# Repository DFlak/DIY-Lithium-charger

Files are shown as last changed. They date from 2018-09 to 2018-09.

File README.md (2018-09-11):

# DIY Lithium charger

<b>First of all, I'm not in any way responsible for any damage that 
could be an outcome of using any part of this circuit.
Lithium batteries are dangerous and shouldn't be handled by unexperienced
persona. Never leave your packs unattended.</b>

I'm aiming to develop a cheap, safe, easy to build and multi-channel lithium charger.
Everyone knows that you can already buy things like iMax B6 clones or whatever. Simple answer is 
those chargers only allow you to charge one battery at a time and their balancing current is less than enough
for anyone that built a battery from used or mismatched cells.

Main goals:<b>

    Independent, balanced channels,
    Easy and cheap to expand,
    Possibly the smallest form factor,
    Wide input and output voltage range, 
    Making it safe to use.

Please remember that it is all work in progress.

## Balancer

The circuit used to build this balancer was created by Afdhal Atiff Tan Amin Husaini Tan from the http://www.afdhalatifftan.com/ blog. His work and his results inspired me to create a board from his schematic. The board uses 10mil trace width which is big enough for toner transfer and unskilled person and also plenty of spacing. The only thing worth mentioning is that resistors which form differential amplifier need to have 0.1% or less tolerance. I was succesful at buying 600pcs of 1k resistors from AliExpress and sorting them by using ADS1115 ADC. Basically you're looking for resistor closest to 1k value with a DMM and then you compare this resistor with any unknown 1k5% one. If value gets close enough LED blinks which indicates that its' resistance is close enough to be 1% tolerance. I can share the code and schematic if anyone needs it but its really basic. Sorting 600 resistors took me about 1,5h and yielded 47 1000+-1ohm and 12 1012+-1ohm resistors. 
A thing worth noting is that it doesn't matter if you choose 1012ohm resistors or 980ohm or whatever value. Only thing that matters is that those resistors need to be 0.1% or even closer to each other. 
I've created this design on regular FR4 1,6mm 35um copper clad. Initially I wanted to etch two sides on one-sided clads and then solder them together by vias but it ended up looking like crap and taking way more time that it needed. 
Will post updates with photos as I etch double-sided clad and test this circuit.
- [x] Create prototype PCB
- [x] Get really dissapointed with the results
- [ ] Order some double-sided PCBs
- [ ] Etch and prototype
- [ ] Post results

## The bare bones 

Basically this charger will push current into lithium packs using [LM2596 based step-down converters](https://www.aliexpress.com/item/1Pcs-LM2596S-DC-DC-Constant-Current-Module-LM2596-DC-DC-7V-35V-Step-down-Adjustable-CC/32849005778.html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). They have usefull feature which is constant current mode and low drift floating voltage. However, them being step-down topology they need their Vin to be at least 2,5V greater than output. Anything lower than that can result in unstable operation of such converter. To remedy this problem I utilized [150W DC-DC Boost converter](https://www.aliexpress.com/item/150W-DC-DC-Boost-Converter-Step-Up-Power-Supply-Module-10-32V-To-12-35V-10A/2038554691.html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) which is set to 19,5V, 2,7volts higher than full 4S Li-po pack. 
In order to stack the LM25965 converters I needed to change the orientation of trimpots from vertical to horizontal. It was done easily with a help of solder wick. Converters are held to each other via epoxy glue on top of the electrolytic capacitors. Heat didn't pose any issues while charging at 1.7A x3 packs. Neither LM25965 nor 150W boost converter were hot to the touch. 

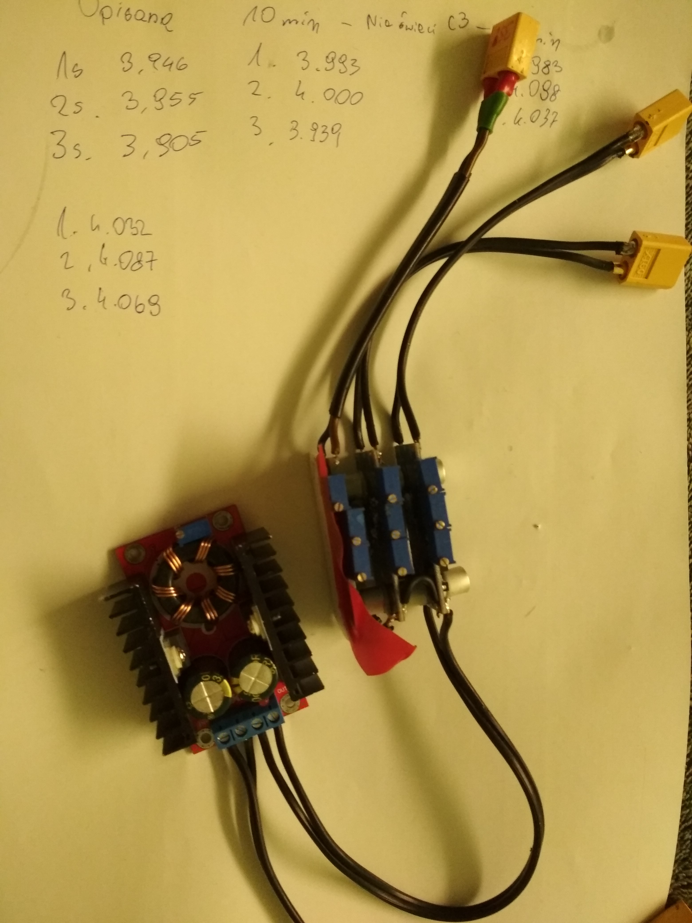
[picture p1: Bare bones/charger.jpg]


I was powering this ciruit from diy-made 4s pack. 
The bare bones of this project are considered done. To expand this charger for more packs you would need to put more LM25965's in parallel keeping in mind the maximum of 150W for each boost converter. My estimate is that one boost converter can supply five charger modules.

## Control, safety and feedback

This charger will use Arduino Nano as a controller. Packs will be switched with a 5V RelPol relays. Each cell will be monitored using [CD74HC4067](https://www.aliexpress.com/item/Smart-Electronics-CD74HC4067-16-Channel-Analog-Digital-Multiplexer-Breakout-Board-Module-for-Arduino/32724398868.html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), calibrated resistive voltage divider and [ADS1115 16bit ADC](https://www.aliexpress.com/item/I2C-ADS1115-ADS1015-16-Bit-ADC-4-channel-Module-with-Programmable-Gain-Amplifier-2-0V-to/32674556200.html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,searchweb201602_4_10065_10068_10843_10059_5016517_10696_100031_5016717_10084_10083_10103_451_10618_452_10304_10307_5016617_10820_10301_10821_5016417,searchweb201603_45,ppcSwitch_5&algo_expid=fb968794-6da6-4dc2-80d7-a833cd81f520-1&algo_pvid=fb968794-6da6-4dc2-80d7-a833cd81f520&transAbTest=ae803_2&priceBeautifyAB=0). I'm planning on adding current monitoring but it all depends whether I can develop reliable and cheap low-side current meter without introducing any more losses. Voltage of each cell will be displayed on regular [16x2 LCD](https://www.aliexpress.com/item/1pcs-lot-New-1602-16x2-Character-LCD-Display-Module-HD44780-Controller-blue-blacklight-IN-STOCK/32328960211.html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,searchweb201602_4_10065_10068_10843_10059_5016517_10696_100031_5016717_10084_10083_10103_451_10618_452_10304_10307_5016617_10820_10301_10821_5016417,searchweb201603_45,ppcSwitch_5&algo_expid=6a017778-b50d-4f92-a064-2eaae25a3f11-0&algo_pvid=6a017778-b50d-4f92-a064-2eaae25a3f11&transAbTest=ae803_2&priceBeautifyAB=0). Arduino will guard if every cell's voltage is in 3.2V < X > 4.2V range. Only then will it allow the relay to connect pack to the charger. Good idea would be to add a capacity meter, capacity limit and charging time limit. First two are dependant on my current meter so I don't know if it will be included.
- [x] Order all of the parts
- [ ] Receive all of the parts 
- [ ] Think of a way to measure current
- [ ] Create schematic
- [ ] Create .brd 
- [ ] Etch and prototype PCB
- [ ] Create arduino code
- [ ] Test the thing thoroughly
- [ ] Post all the files here

### If anyone is interested in helping me feel free to contact me via mail at wtflolrotfl@gmail.com :)

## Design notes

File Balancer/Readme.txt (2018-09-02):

The schematic was made by Afdhal Atiff Tan.
His blog can be found at this link and I encourage you to go take a look.

<b>http://www.afdhalatifftan.com/2017/06/low-cost-active-battery-balancer.html</b>

Board was made by me. It can be viewed by Eagle, I used version 7.7, resistors are THT because it's far easier to source 0.1% THT's than SMD's.

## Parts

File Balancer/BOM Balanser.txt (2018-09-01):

Partlist exported from C:/Users/Jabby/Desktop/Eagle/w trakcie/balanser/balanser 4s drugi prototyp, smd kondziorki.sch at 2018-09-01 18:04

Qty Value                  Device                 Package                Parts                                                  Description                                           MF MPN OC_FARNELL OC_NEWARK
1                          JU05                   JU05                   J1                                                     PIN HEADER                                                   unknown    unknown  
3   100R                   R-EU_M0805             M0805                  R5, R14, R23                                           RESISTOR, European symbol                                                        
6   100n                   C-EUC0805K             C0805K                 C1, C2, C7, C8, C9, C10                                CAPACITOR, European symbol                                                       
6   10k                    R-EU_M0805             M0805                  R7, R8, R16, R17, R25, R26                             RESISTOR, European symbol                                                        
3   10uF                   CPOL-EUE2,5-6E         E2,5-6E                C5, C12, C14                                           POLARIZED CAPACITOR, European symbol                                             
12  1k                     R-EU_0204/7            0204/7                 R1, R2, R3, R4, R10, R11, R12, R13, R19, R20, R21, R22 RESISTOR, European symbol                                                        
6   1k                     R-EU_M0805             M0805                  R6, R9, R15, R18, R24, R27                             RESISTOR, European symbol                                                        
5   2.6A Polyfuse          1812L                  1812L                  F2, F3, F4, F5, F6                                                                                                                      
3   22uF                   CPOL-EUE2,5-6E         E2,5-6E                C6, C11, C13                                           POLARIZED CAPACITOR, European symbol                                             
3   DC-DC-STEP-DOWN-MP2307 DC-DC-STEP-DOWN-MP2307 DC-DC-STEP-DOWN-MP2307 U$1, U$2, U$3                                          DC/DC Step-Down Regulator based on MP2307DN chip                                 
3   LM358D                 LM358D                 SO08                   IC1, IC2, IC3                                          OP AMP also LM158; LM258; LM2904                                                 
3   LSP10                  LSP10                  LSP10                  VFB1, VFB2, VFB3                                       SOLDER PAD drill 1.0 mm, distributor Buerklin, 12H555

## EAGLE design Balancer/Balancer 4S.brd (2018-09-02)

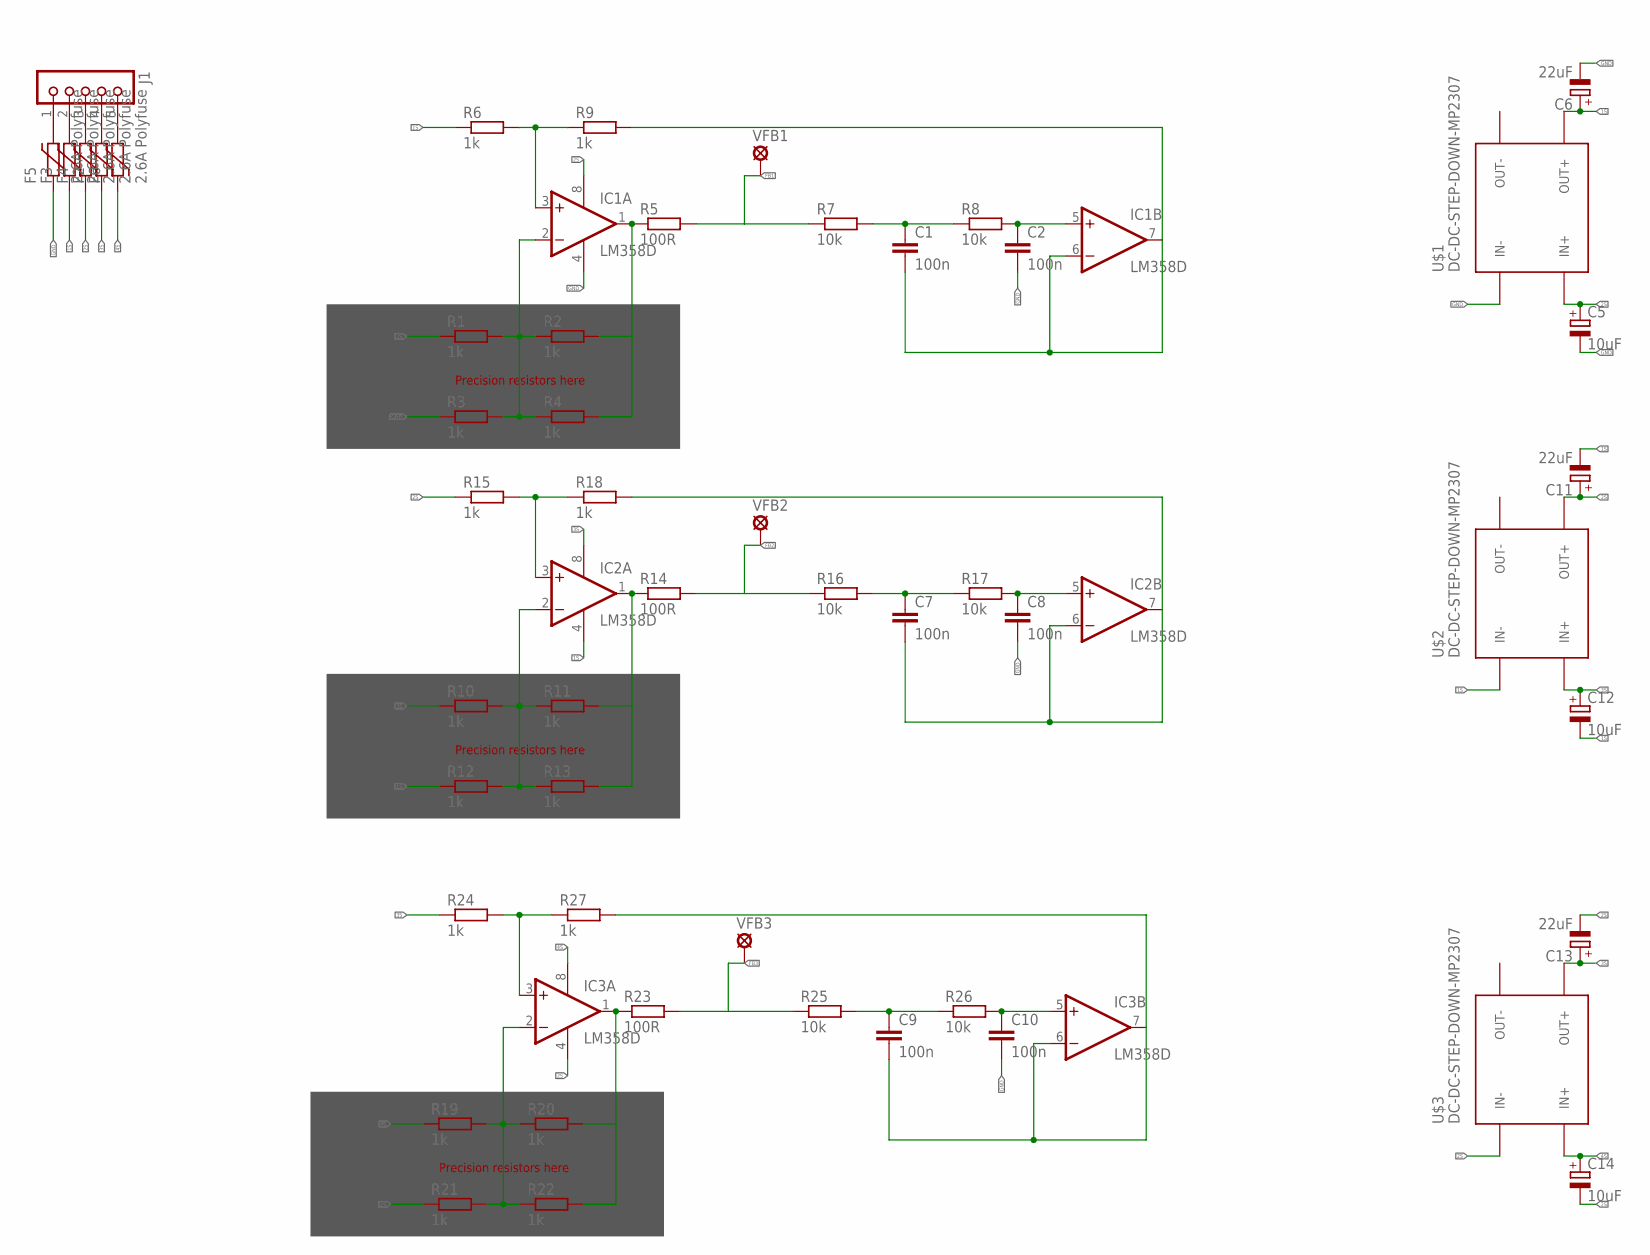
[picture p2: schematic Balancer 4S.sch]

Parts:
C1, C2, C7, C8, C9, C10: 100n; C0805K
C5, C12, C14: 10uF; E2,5-6E
C6, C11, C13: 22uF; E2,5-6E
F2, F3, F4, F5, F6: 2.6A Polyfuse; 1812L
IC1, IC2, IC3: LM358D; SO08
J1: JU05
R1, R2, R3, R4, R10, R11, R12, R13, R19, R20, R21, R22: 1k; 0204/7
R5, R14, R23: 100R; M0805
R6, R9, R15, R18, R24, R27: 1k; M0805
R7, R8, R16, R17, R25, R26: 10k; M0805
U$1, U$2, U$3: DC-DC-STEP-DOWN-MP2307
VFB1, VFB2, VFB3: MCS08

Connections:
1S: C6.+, C11.-, C12.-, F3.P$1 (1), IC2.4 (V-), R6.1, R12.1, U$1.OUT+, U$2.IN-
2S: C5.+, C11.+, C13.-, C14.-, F4.P$1 (1), IC1.8 (V+), IC3.4 (V-), R1.1, R15.1, R21.1, U$1.IN+, U$2.OUT+, U$3.IN-
3S: C12.+, C13.+, F2.P$1 (1), IC2.8 (V+), R10.1, R24.1, U$2.IN+, U$3.OUT+
4S: C14.+, F6.P$1 (1), IC3.8 (V+), R19.1, U$3.IN+
FB1: R5.2, R7.1, VFB1.MP
FB2: R14.2, R16.1, VFB2.MP
FB3: R23.2, R25.1, VFB3.MP
GND: C2.2, C5.-, C6.-, C8.2, C10.2, F5.P$1 (1), IC1.4 (V-), R3.1, U$1.IN-
unnamed: IC1.3 (+IN), R6.2, R9.1
unnamed: F5.P$2 (2), J1.1
unnamed: IC1.2 (-IN), R1.2, R2.1, R3.2, R4.1
unnamed: IC1.1 (OUT), R2.2, R4.2, R5.1
unnamed: C1.1, R7.2, R8.1
unnamed: C2.1, IC1.5 (+IN), R8.2
unnamed: C1.2, IC1.6 (-IN), IC1.7 (OUT), R9.2
unnamed: F4.P$2 (2), J1.3
unnamed: F3.P$2 (2), J1.2
unnamed: F2.P$2 (2), J1.4
unnamed: F6.P$2 (2), J1.5
unnamed: IC2.3 (+IN), R15.2, R18.1
unnamed: IC2.2 (-IN), R10.2, R11.1, R12.2, R13.1
unnamed: IC2.1 (OUT), R11.2, R13.2, R14.1
unnamed: C7.1, R16.2, R17.1
unnamed: C8.1, IC2.5 (+IN), R17.2
unnamed: C7.2, IC2.6 (-IN), IC2.7 (OUT), R18.2
unnamed: IC3.3 (+IN), R24.2, R27.1
unnamed: IC3.2 (-IN), R19.2, R20.1, R21.2, R22.1
unnamed: IC3.1 (OUT), R20.2, R22.2, R23.1
unnamed: C9.1, R25.2, R26.1
unnamed: C10.1, IC3.5 (+IN), R26.2
unnamed: C9.2, IC3.6 (-IN), IC3.7 (OUT), R27.2

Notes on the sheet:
Precision resistors here

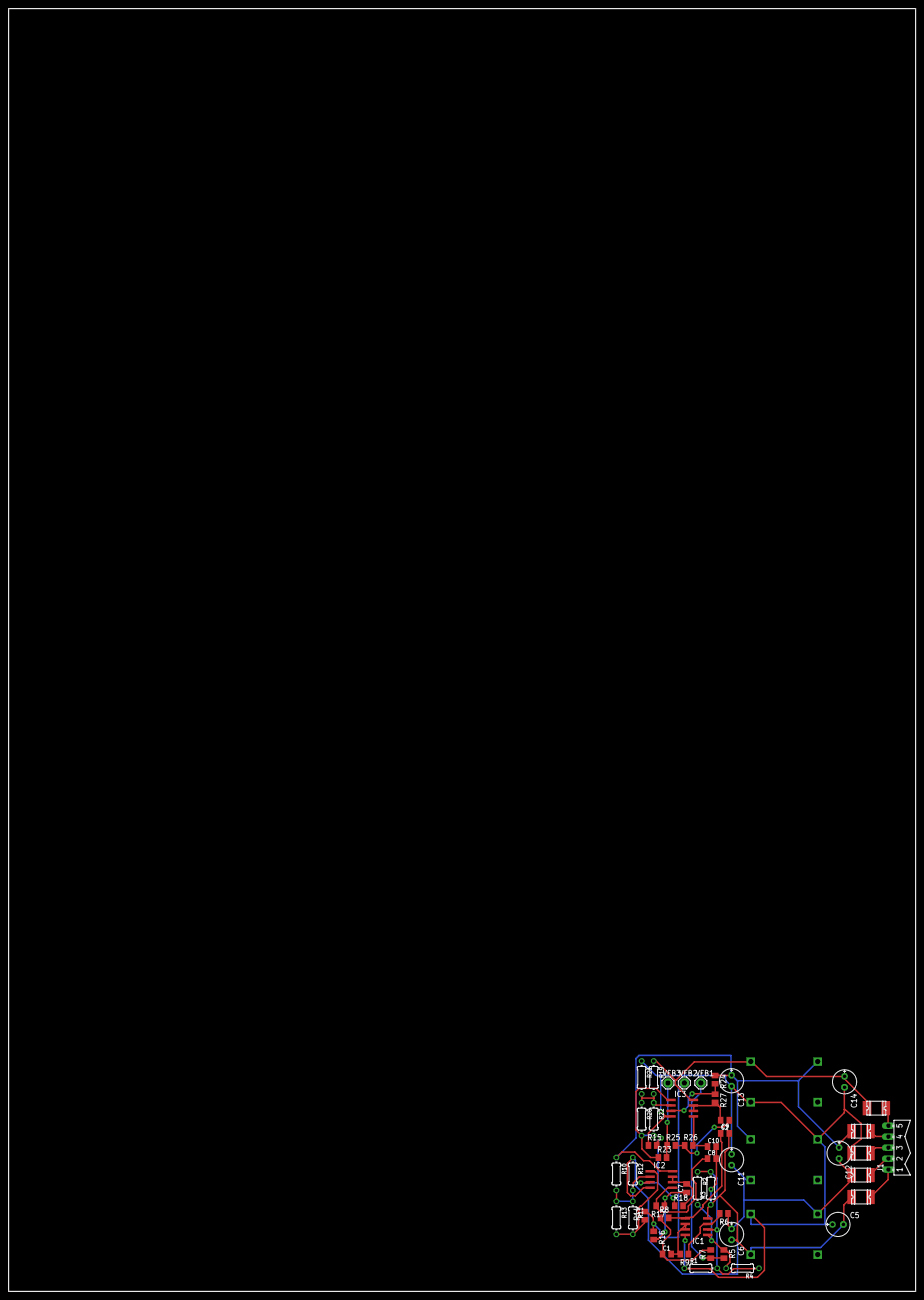
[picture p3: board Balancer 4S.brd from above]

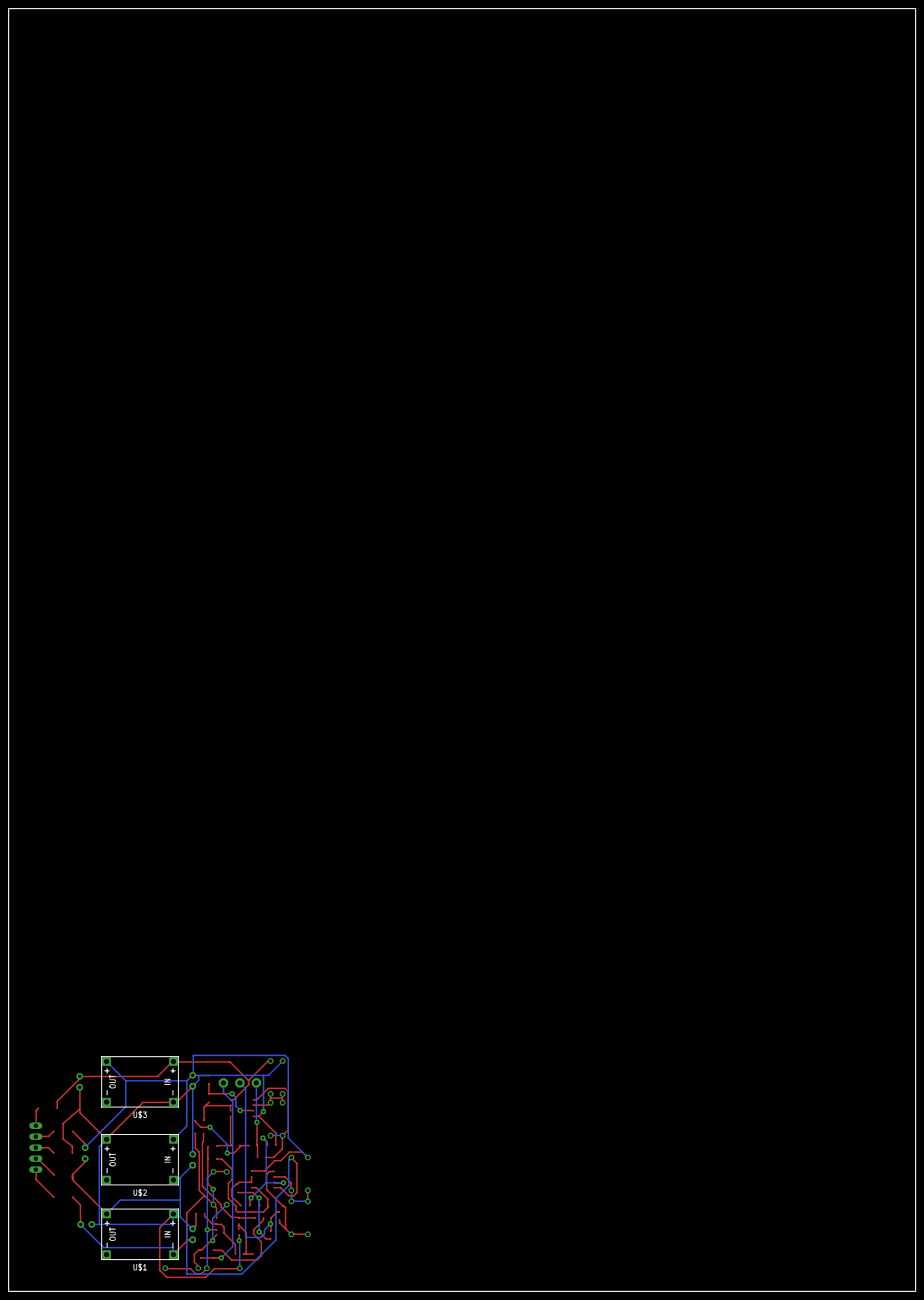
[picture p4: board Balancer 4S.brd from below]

Board: 2 copper layers, 210.0 x 297.0 mm, 54 parts (3 on the bottom side), 31 nets.

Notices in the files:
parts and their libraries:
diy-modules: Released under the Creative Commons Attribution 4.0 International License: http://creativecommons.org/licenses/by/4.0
